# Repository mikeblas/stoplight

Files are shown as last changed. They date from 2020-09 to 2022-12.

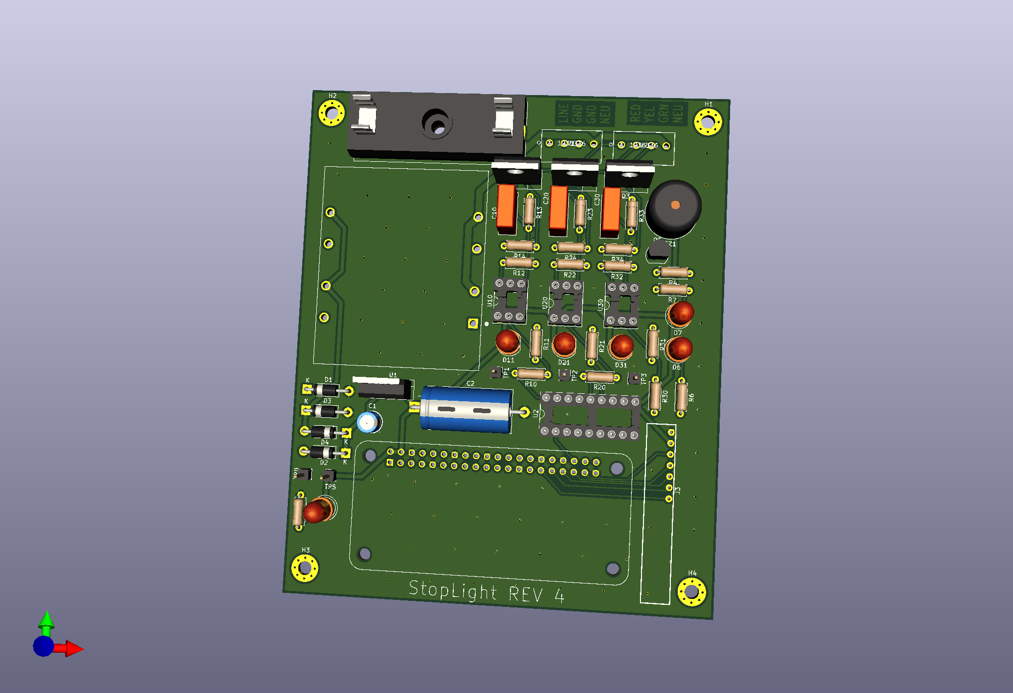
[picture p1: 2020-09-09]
pcb/StopLight4/StopLight4.png

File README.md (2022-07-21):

# stoplight
This project provides hardware and software for a stoplight controlled by a Raspberry Pi.

## Context
In the late 1990s, I purchased a traffic signal from a curiosities shop. It's a full-scale signal, appropriate for
"real" outdoor use; each lens is about 20cm in diameter, and it's a giant green beast. During the lockdowns in 2020,
I finally found the time to get it working in a fun and useful way.

This project includes a printed circuit board design that hosts a Raspberry Pi Zero W and implements a
mains-based power supply and switching circuits for each of the lamps in the signal. I chose the Pi Zero because
it gets me onto the wireless network, and has enough computing power to do interesting things with the signal. With
a little research, it should be possible to find a smaller board that has WiFi connectivity, but I already had an
unused Pi Zero, so I just went with it.

The board further hosts a generic wireless remote control board built around the PT2272 receiver chip. The chip
gives four latched outputs from a four-button key fob style RF remote. This remote can be used to control
the stoplight.

And of course, the project includes software to make it do something.

## Status

This project is "done enough" for now. All the features below are implemented, and the wish list features are
not yet implemented.

## Hardware Features

The hardware is done; amazingly, I didn't have to re-print the board and got it right on the first try. The
only problem was using a 7805 regulator. The voltage drop made it run red hot, so I replaced it with a three-pin
PC-based switching regulator, which works fine. The filter capacitor on the output of the supply wasn't adequate,
so I increased it. That, of course, required a part with a bigger footprint so the mounting is a bit lumpy,
but it works fine.

## Software Features

The software implements several modes, selectable by the remote. First, we can turn the thing off:

* Turn off the light; minimal processing, nothing illuminated.
* Turn the light back on; whatever mode was active last resumes.

Then, we have one of a few modes active:

* Traffic light. Red, green, yellow, in a realistically timed cycle.
* Random single flash. Flash a single (selectable) lamp at a regular interval.
* Random flash. Flash a randomly selected lamp one at a time.
* Random flash. Flash each lamp at random intervals. This is "disco mode"! 
* Manual selection. Turn a lamp off or on, and it stays that way.

We mostly leave the light in disco mode, and it's fun to see it blinking away.

## Wish List

I'd like to add a few more modes:

* Clock. Flash lights to make a binary time-of-day clock.
* Weather indicator. Show tomorrow's predicted weather (temperature and precipitation)
* Stock market indicator. If the market is open, show the directional change in a particular index.

There's also a couple of interesting things that I'd like to add:

* Mode memory. It would be great to have the system restore its mode when it starts up again after
a reboot or power failure.
* Monitoring. Anything I can monitor in my home network is monitored -- lots of SNMP collectors and
some Influx scripts pull data in to Grafana. Adding 
* Web page. It would be cool to have a little web server to present a UI for changing modes, looking
at statistics, and so on.
* Mobile app. A web API would enable a mobile application for modes and stats, too.

Since the project is built and installed, then I'm not very motivated to work on these things. Maybe
in the winter I'll get another Pi Zero and set it up so I can run the core on my bench, and get to
work on those feature. The design has on-board LEDs for all of the outputs, so pretty much no support
circuitry is necessary. I just need to build and populate one of my spare PC boards. 

## Project Layout

`stoplightd` is the stoplight daemon program. This is the controller that runs on the Pi (as I'm working on it)

`proto` are various fragments and scratch projects as I sort out GPIO, how the hardware works, and try out ideas.

`pcb` is the hardware project for KiCad.

## Images

Installing KiCad just to take a peek is a big ask, so here are some links:

* A snapshot of [the PC board](docs/pics/pc_board.png "PC Board")
* A snapshot of [the schematic](docs/pics/schematic.png "Schematic")

# Dependencies

This project uses [libdaemonize](https://github.com/Aethelflaed/libdaemonize).

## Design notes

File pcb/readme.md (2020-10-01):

# Stoplight Controller PC Board

This directory contains different versions of the StopLight PC Board. I split the design since I wasn't comfortable using `git` to manage the projects, and I also wasn't positive I wouldn't fork or rework the older designs anyway. I ended up linear, though, and StopLight4 is the version of the board sent to be fabricated.

## StopLight1

Uses discrete transistors to drive the relays and indicator LEDs.

## StopLight2

Substitutes a `ULN2803` driver chip for the relays to save a lot of space.

## StopLight3

Relays turned out to be pretty noisy, so I built a TRIAC circuit to drive the lights. Maybe the `ULN2803` isn't necessary anymore, but it remains. (Uhoh. Looks like some files are missing!)

## StopLight4

There were fuses on each of the three light lines, which is a bit redundant. Seems nice, but the fuse holders take up a ton of PC board space so I've eliminated them. This resulted in a more pleasing layout and a smaller board. This board version was sent to production.

## StopLight5

This version will fix a few issues, if another production run is needed:

1) Holes in remote header too smaller (0.75mm, should be 1.00mm)
2) Phoenix connectors are facing the wrong way
3) Rotate TP5 so its silk screen matches other TPs
4) Mask over the copper legend for high-voltage outputs
5) "hash" silkscreen over high voltage area of board
6) Renumber F4 to F1

# Hardware PostMortem

Most of the interesting problems are listed above, but some are not; and some are interesting to investigate a little more.

## Power Supply

Most of the issues were with the power supply, really.

**Power Budget**. I just figured I'd get a transformer, rectifier, a couple of filter caps, and drive a 7805 and be done. It's a little more complicated than that. First off, I bugeted a bit high for power because I thought I would be holding relays up. Once I eliminated the relays, I shouldn't made a closer estimate. The supply should drive about 1.5 amps without a problem (except for heat), and I could use a much smaller transformer since my budget is really closer to 500 milliamps.

**Filter**. I couldn't find good advice about sizing the filter caps, and they're too small. Maybe the over-arching problem is that I didn't prototype the power supply on my breadboard. Had I done so, I would've caught most (if not all) of these problems.

**Heat**. My transformer develops 10 volts at the secondary, which initially sounded low. The dropout of the regulator means I need at least 7 volts at the input, and I'm making lots of heat in the linear regulator. A switching regulator is probably the best solution, and I'm probably going to end up getting one of the "cheater" switching converters on a TO-220-sized board to solve the heat issue.

## Layout

I'm pretty pleased with the layout. I was always tempted to "hide" components under the Raspberry Pi module, but I'm glad I didn't because it would  have made troubleshooting harder. Getting a probe onto anything under there would be obnoxious -- my only choice would be to get to the back of the board.

After that, the layout is pretty nice. I'm glad I got rid of the redundant fuses. It might have helped more the use an in-line fuse holder, but those also have some inconveniences. A smaller fuse form factor might have been a good idea, tho.

## In General

It was great to get rid of the relays. The clicking was completely obnoxious; I can't imagine these being used in anything but an industrial or large commercial application. Learning how to control the TRIACS was fun. 

I could probably get rid of the driver, but it's not much real estate and gives me a bit more confidence in the design for now.

## Software

The software is going well, though I don't have as much time to spend on it. When I do, I'm productive and can get some things done.

## Mechanical

The mechanical assembly came together quite well, and I'm happy with it. Even the carpentry isn't so bad.

## Light Bulbs

I'm worried that the light is too bright. Maybe a cool V2 feature would be to support PWM dimming so the brightness would be settable through software. Choosing bulbs was hard; there aren't many incadescent choices anymore. LED bulbs don't go so dim, either. The 25-watt equivalent LED bulb seems best, but it's quite expensive (about $8) and who knows how long they'll make it. A couple LED bulbs I tried didn't turn on or off correctly, so experimenting is kind of hit-and-miss.

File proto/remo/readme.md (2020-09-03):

== remo ==

A first cut at readingt the RF remote inputs from the GPIO.

This polls, which is kind of lame -- and I need to sort out the object structure.

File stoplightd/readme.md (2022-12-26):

# stoplightd

The daemon runs the stoplight. It listens to the remote and blinks lights -- it's almost that simple!

It logs, too, to syslog. And it can run the stoplight in a bunch if different modes. Since the remote is klunky and unreliable, and because the light only has a beeper and the three traffic lights, we have to be creative about UI.

When the light is in **idle** mode, it is dark. It's not beeping, and all the lights are off. Idle mode can be exited with any button press; any button pres moves to **selection** mode.

So now let's examine the different modes:

## Selection
Selection mode lets the user select a mode.

* Binary display to select mode. A is up, B is down. When zero, red flashes 100 ms every 2 seconds (or so?)
* C selects mode.
* D exits to idle mode.
	
## Mode 0: Plain traffic light	
* A increases speed,
* B decreases speed. Speed is ratio of R48/Y8/G24 (6x, 1x, 4x), 1 second steps, 1-10
* D quits back to mode selection.

## Mode 1: Single Blinky	
* A increases speed, B decreases speed. 250ms to 5s in 250ms increments
* C sets duty cycle, looping through 100, 75, 50, 25%
* D quits back to mode selection.
	
## Mode 2: Multi Blinky
* A increases speed, B decreases speed. 250ms to 5s in 250ms increments
* C sets duty cycle, looping through 100, 75, 50, 25%
* D quits back to mode selection.

## Mode 3: Selecto
* A, B, C toggles each light
* D quits back to mode selection

## Mode 4: Clock
 * All off, but every 30 sconds shows time
 * flashes Hour, then minute in binary.
 * D quits

This is how numbers are displayed:
 * 0-7: binary; 1 = ryG, 3 = rYG, 4 = Ryg
 * 8: rapidly flashing red, y = off, g = on
 * 9: rapidly flashing red, y = on, g = off
 * each digit shown 1 second, display of 4 digits takes 4 seconds

## Mode 5: Weather
 * Temperature change for 2 seconds
 * Precip chance for 3 seconds  (green = 0-20%, yel= 20-60%, red > 60%)
 * 5 seconds dark
 * D quits

## Mode 6: Stock Ticker

(Not yet implemented.)

## Mode 7: Weather

(Not yet implemented.)

# Building

This project requires [libdaemonize](https://github.com/Aethelflaed/libdaemonize) and gpiod.

## libdaemonize

1. Clone the `libdaemonize` project from git.
2. It requires `libtool` to get working, so install that with `sudo apt install libtool -y`
3. In the `libdaemonize` root directory, run these commands:  
```
libtoolize
aclocal
autoconf
automake --add-missing
```
4. Now, the library can be configured and built:
```
./configure --prefix=/usr
make
```
5. And finally installed, so that the library and its headers are readable.
```
sudo make install
```

## libgpiod

The code needs `libgpiod` to communicate with the Raspberry Pi GPIO. It can be installed easily:

```
sudo apt install libgpiod-dev -y
``` 

## Actually building

With the dependencies installed and built, the project itself can be built:

```
make clean all
```

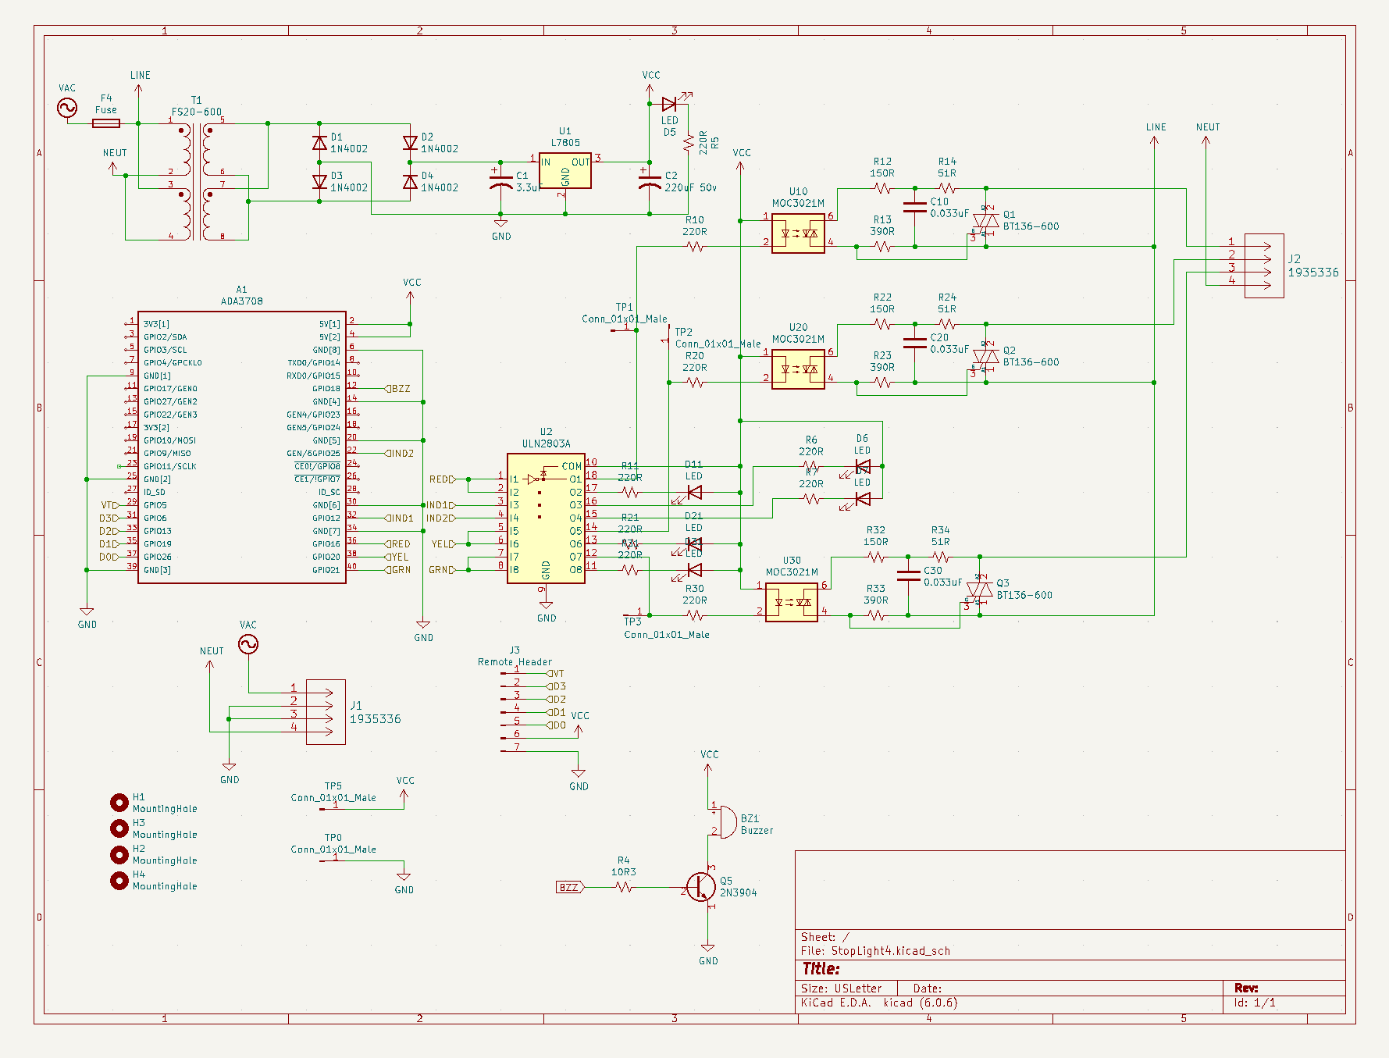
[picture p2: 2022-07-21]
docs/pics/schematic.png

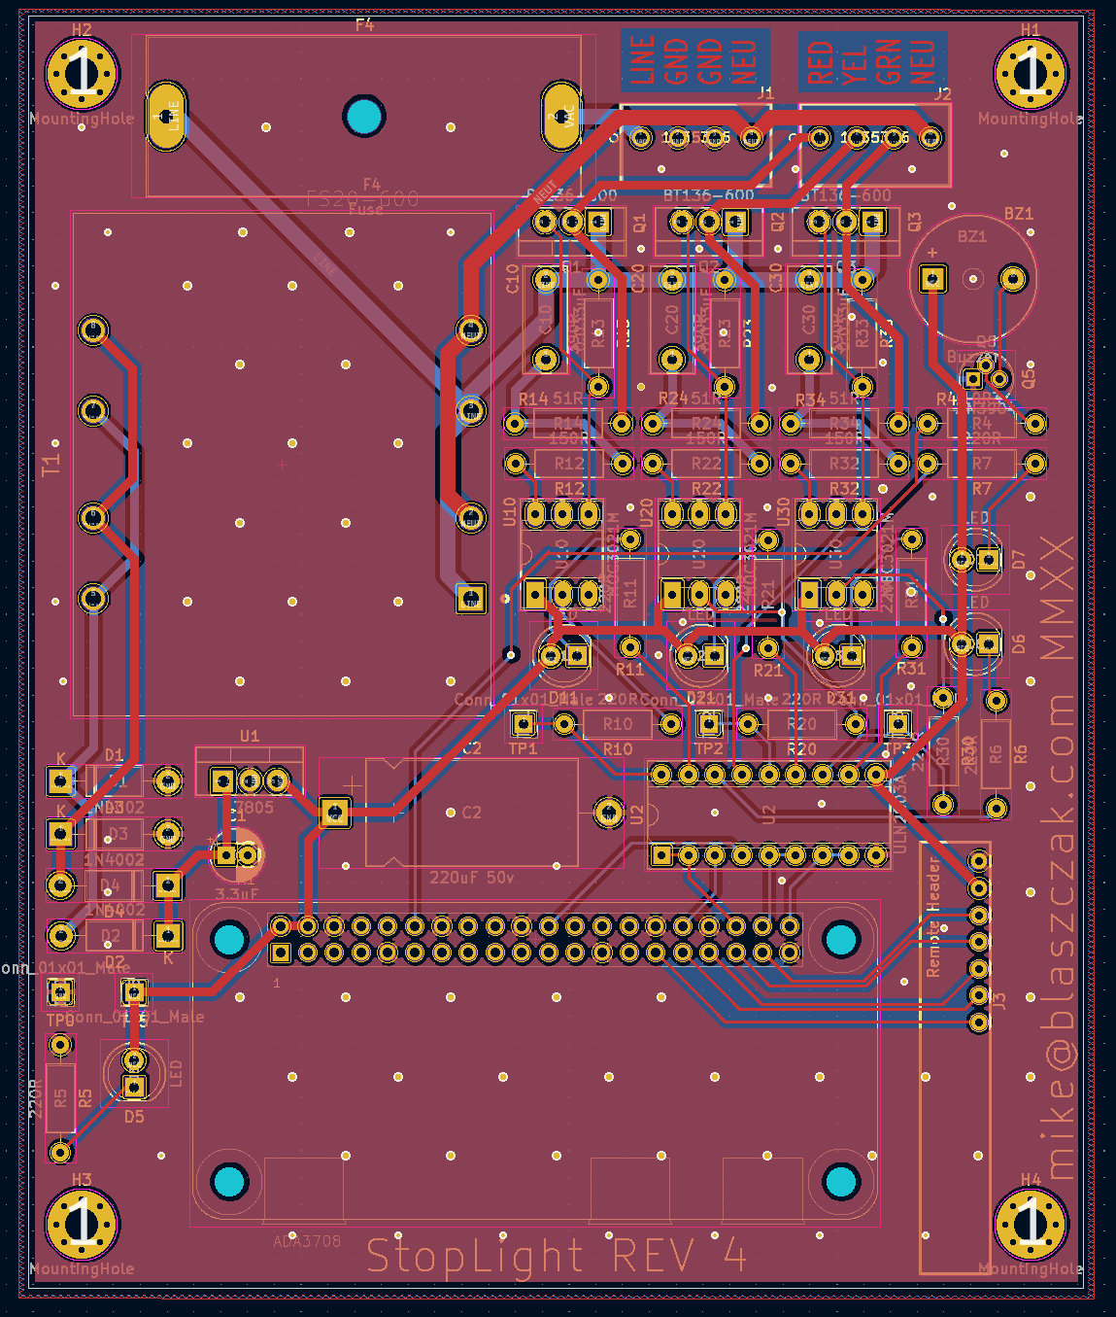
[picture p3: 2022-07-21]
docs/pics/pc_board.png

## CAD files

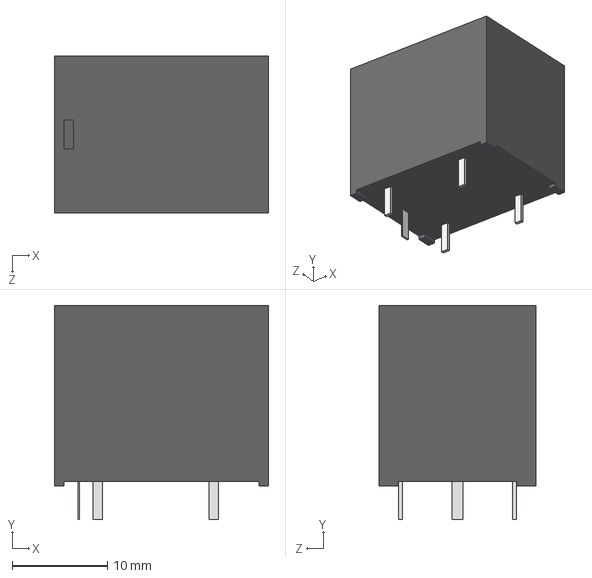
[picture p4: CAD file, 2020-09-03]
pcb/StopLight1/G5LE_14.step
22.5 x 22.5 x 16.5 mm

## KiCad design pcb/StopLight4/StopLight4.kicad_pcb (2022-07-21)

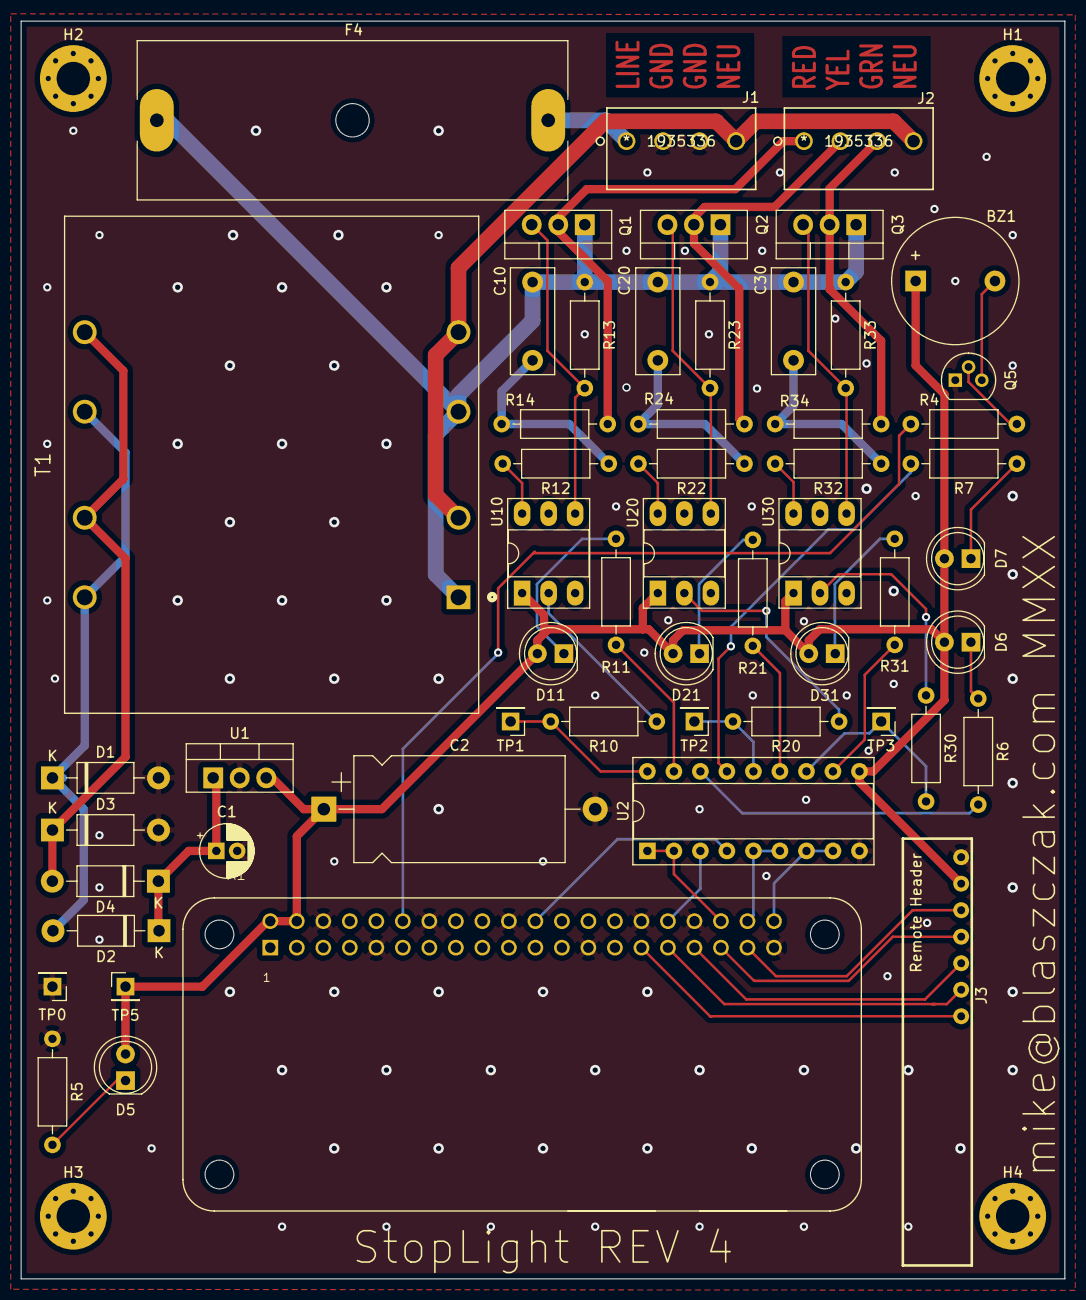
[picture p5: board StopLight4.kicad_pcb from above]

Board: 2 copper layers, 100.0 x 120.5 mm, 59 parts (0 on the bottom side), 50 nets.

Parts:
A1: ADA3708; ADA3708_RPI-ZERO
BZ1: Buzzer; Buzzer_12x9.5RM7.6
C1: 3.3uF; CP_Radial_D5.0mm_P2.00mm
C2: 220uF 50v; CP_Axial_L20.0mm_D10.0mm_P26.00mm_Horizontal
C10, C20, C30: 0.033uF; C_Rect_L10.0mm_W4.0mm_P7.50mm_MKS4
D1, D2, D3, D4: 1N4002; D_DO-41_SOD81_P10.16mm_Horizontal
D5, D6, D7, D11, D21, D31: LED; LED_D5.0mm
F4: Fuse; Fuseholder_Cylinder-6.3x32mm_Schurter_0031-8002_Horizontal_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
H1, H2, H3, H4: MountingHole; MountingHole_3.2mm_M3_Pad_Via
J1, J2: 1935336; 1984633
J3: Remote Header; WirelessRemote
Q1, Q2, Q3: BT136-600; TO-220-3_Vertical
Q5: 2N3904; TO-92
R4: 10R3; R_Axial_DIN0207_L6.3mm_D2.5mm_P10.16mm_Horizontal
R5, R6, R7, R10, R11, R20, R21, R30, R31: 220R; R_Axial_DIN0207_L6.3mm_D2.5mm_P10.16mm_Horizontal
R12, R22, R32: 150R; R_Axial_DIN0207_L6.3mm_D2.5mm_P10.16mm_Horizontal
R13, R23, R33: 390R; R_Axial_DIN0207_L6.3mm_D2.5mm_P10.16mm_Horizontal
R14, R24, R34: 51R; R_Axial_DIN0207_L6.3mm_D2.5mm_P10.16mm_Horizontal
T1: FS20-600; XFMR_FS20-600
TP0, TP1, TP2, TP3, TP5: Conn_01x01_Male; PinHeader_1x01_P2.54mm_Vertical
U1: L7805; TO-220-3_Vertical
U2: ULN2803A; DIP-18_W7.62mm_Socket
U10, U20, U30: MOC3021M; DIP-6_W7.62mm_Socket_LongPads

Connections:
/D0: A1.37, J3.5
/D1: A1.35, J3.4
/D2: A1.33, J3.3
/D3: A1.31, J3.2
/GRN: A1.40, U2.7, U2.8
/IND1: A1.32, U2.3
/IND2: A1.22, U2.4
/RED: A1.36, U2.1, U2.2
/VT: A1.29, J3.1
/YEL: A1.38, U2.5, U2.6
BZZ: A1.12, R4.2
GND: A1.6, A1.9, A1.14, A1.20, A1.25, A1.30, A1.34, A1.39, C1.2, C2.2, D1.2, D3.2, J1.2, J1.3, J3.7, Q5.1, R5.1, TP0.1, U1.2, U2.9
LINE: C10.2, C20.2, C30.2, F4.1, Q1.1, Q2.1, Q3.1, R13.1, R23.1, R33.1, T1.1, T1.3
NEUT: J1.4, J2.4, T1.2, T1.4
unnamed: BZ1.2, Q5.3
unnamed: C1.1, D2.1, D4.1, U1.1
unnamed: C10.1, R12.1, R14.2
unnamed: C20.1, R22.1, R24.2
unnamed: C30.1, R32.1, R34.2
unnamed: D1.1, D2.2, T1.5, T1.7
unnamed: D3.1, D4.2, T1.6, T1.8
unnamed: D5.1, R5.2
unnamed: D6.1, R6.1
unnamed: D7.1, R7.1
unnamed: D11.1, R11.1
unnamed: D21.1, R21.1
unnamed: D31.1, R31.1
unnamed: J2.1, Q1.2, R14.1
unnamed: J2.2, Q2.2, R24.1
unnamed: J2.3, Q3.2, R34.1
unnamed: Q1.3, R13.2, U10.4
unnamed: Q2.3, R23.2, U20.4
unnamed: Q3.3, R33.2, U30.4
unnamed: Q5.2, R4.1
unnamed: R6.2, U2.16
unnamed: R7.2, U2.15
unnamed: R10.1, U10.2
unnamed: R10.2, TP1.1, U2.18
unnamed: R11.2, U2.17
unnamed: R12.2, U10.6
unnamed: R20.1, U20.2
unnamed: R20.2, TP2.1, U2.14
unnamed: R21.2, U2.13
unnamed: R22.2, U20.6
unnamed: R30.1, U30.2
unnamed: R30.2, TP3.1, U2.12
unnamed: R31.2, U2.11
unnamed: R32.2, U30.6
VAC: F4.2, J1.1
VCC: A1.2, A1.4, BZ1.1, C2.1, D5.2, D6.2, D7.2, D11.2, D21.2, D31.2, J3.6, TP5.1, U1.3, U2.10, U10.1, U20.1, U30.1

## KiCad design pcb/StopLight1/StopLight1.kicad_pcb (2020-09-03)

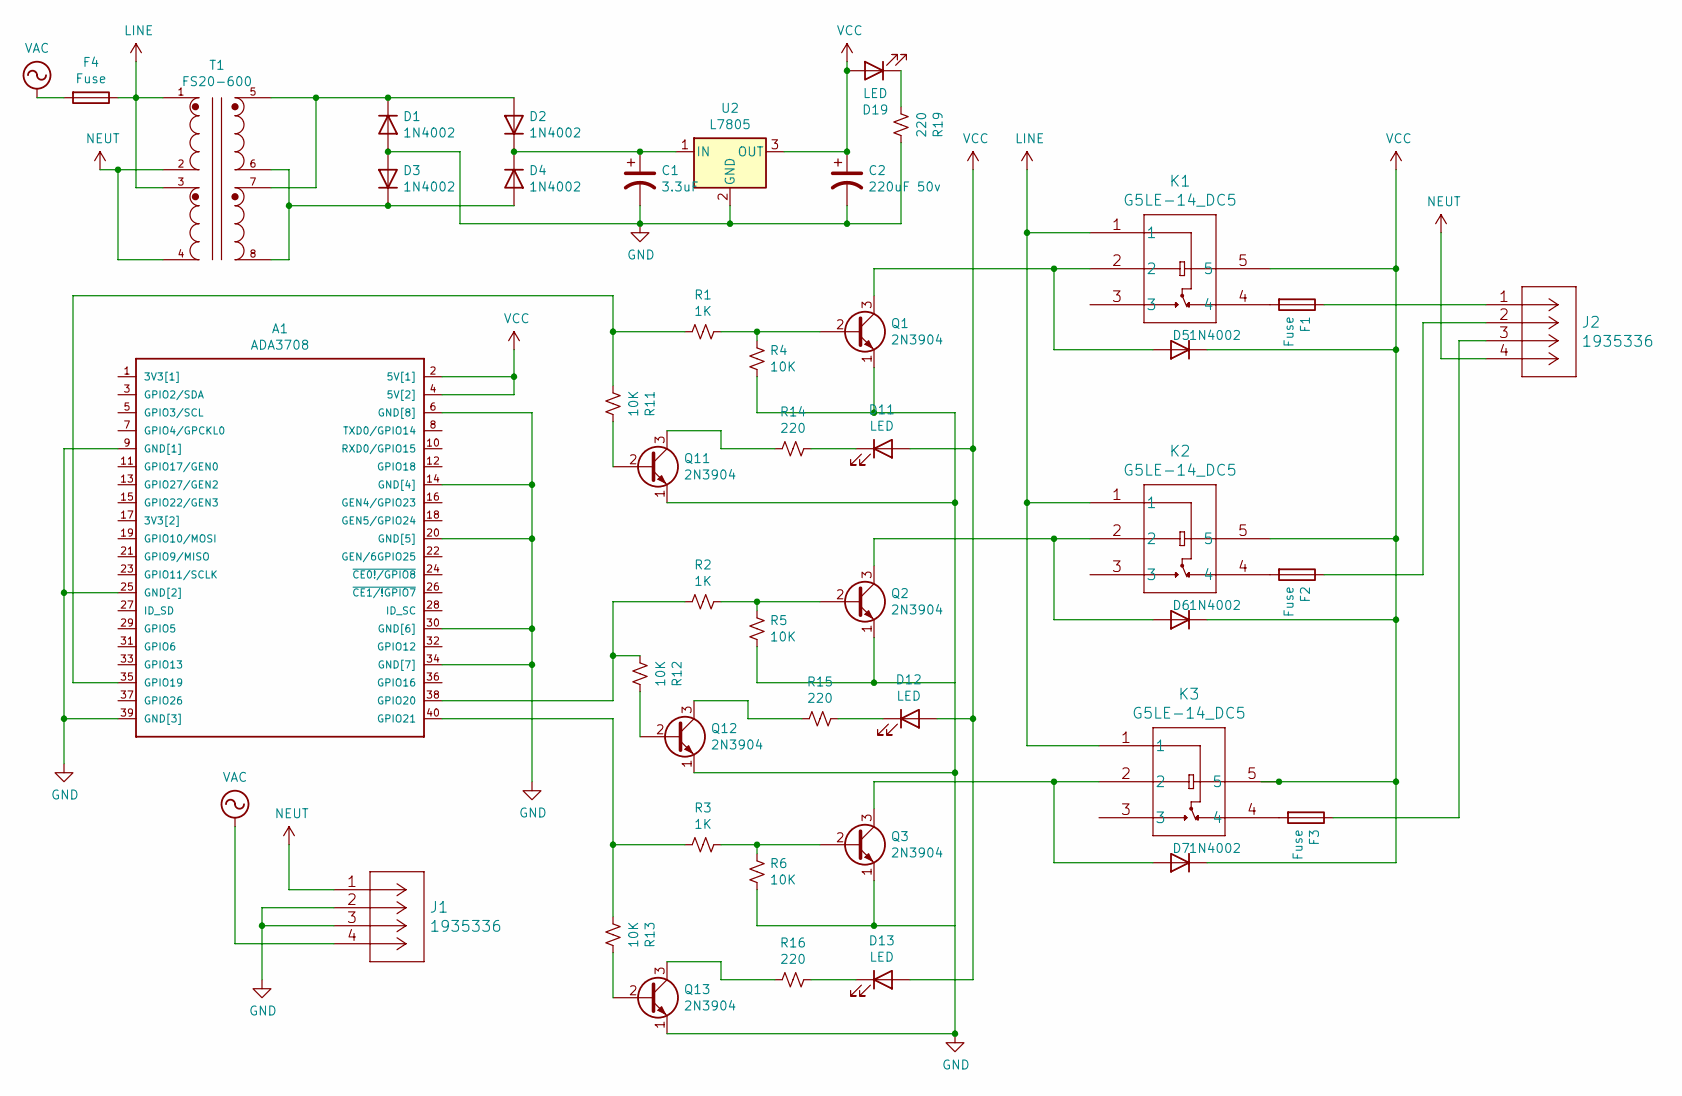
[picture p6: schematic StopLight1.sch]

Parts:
A1: ADA3708; ADA3708_RPI-ZERO
C1: 3.3uF; CP_Radial_D5.0mm_P2.00mm
C2: 220uF 50v; CP_Axial_L20.0mm_D10.0mm_P26.00mm_Horizontal
D1, D2, D3, D4, D5, D6, D7: 1N4002; D_DO-41_SOD81_P10.16mm_Horizontal
D11, D12, D13, D19: LED; LED_D5.0mm
F1, F2, F3, F4: Fuse; Fuseholder_Cylinder-6.3x32mm_Schurter_0031-8002_Horizontal_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
J1, J2: 1935336
K1, K2, K3: G5LE-14_DC5; G5LE-14 DC5
Q1, Q2, Q3, Q11, Q12, Q13: 2N3904; TO-92
R1, R2, R3: 1K; R_Axial_DIN0207_L6.3mm_D2.5mm_P10.16mm_Horizontal
R4, R5, R6, R11, R12, R13: 10K; R_Axial_DIN0207_L6.3mm_D2.5mm_P10.16mm_Horizontal
R14, R15, R16, R19: 220; R_Axial_DIN0207_L6.3mm_D2.5mm_P10.16mm_Horizontal
T1: FS20-600; XFMR_FS20-600
U2: L7805; TO-220-3_Vertical

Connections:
GND: A1.6 (GND[8]), A1.9 (GND[1]), A1.14 (GND[4]), A1.20 (GND[5]), A1.25 (GND[2]), A1.30 (GND[6]), A1.34 (GND[7]), A1.39 (GND[3]), C1.2, C2.2, D1.2 (A), D3.2 (A), J1.2, J1.3, Q1.1 (E), Q11.1 (E), Q12.1 (E), Q13.1 (E), R4.2, R19.1, U2.2 (GND)
LINE: F4.1, K1.1, K2.1, K3.1, T1.1, T1.3
NEUT: J1.1, J2.4, T1.2, T1.4
unnamed: A1.35 (GPIO19), R1.2, R11.2
unnamed: A1.38 (GPIO20), R2.2, R12.2
unnamed: A1.40 (GPIO21), R3.2, R13.2
unnamed: C1.1, D2.1 (K), D4.1 (K), U2.1 (IN)
unnamed: D1.1 (K), D2.2 (A), T1.5, T1.7
unnamed: D3.1 (K), D4.2 (A), T1.6, T1.8
unnamed: D5.2 (A), K1.2, Q1.3 (C)
unnamed: D6.2 (A), K2.2, Q2.3 (C)
unnamed: D7.2 (A), K3.2, Q3.3 (C)
unnamed: D11.1 (K), R14.1
unnamed: D12.1 (K), R15.1
unnamed: D13.1 (K), R16.1
unnamed: D19.1 (K), R19.2
unnamed: F1.1, J2.1
unnamed: F1.2, K1.4
unnamed: F2.1, J2.2
unnamed: F2.2, K2.4
unnamed: F3.1, J2.3
unnamed: F3.2, K3.4
unnamed: Q1.2 (B), R1.1, R4.1
unnamed: Q2.1 (E), R5.2
unnamed: Q2.2 (B), R2.1, R5.1
unnamed: Q3.1 (E), R6.2
unnamed: Q3.2 (B), R3.1, R6.1
unnamed: Q11.2 (B), R11.1
unnamed: Q11.3 (C), R14.2
unnamed: Q12.2 (B), R12.1
unnamed: Q12.3 (C), R15.2
unnamed: Q13.2 (B), R13.1
unnamed: Q13.3 (C), R16.2
VAC: F4.2, J1.4
VCC: A1.2 (5V[1]), A1.4 (5V[2]), C2.1, D5.1 (K), D6.1 (K), D7.1 (K), D11.2 (A), D12.2 (A), D13.2 (A), D19.2 (A), K1.5, K2.5, K3.5, U2.3 (OUT)

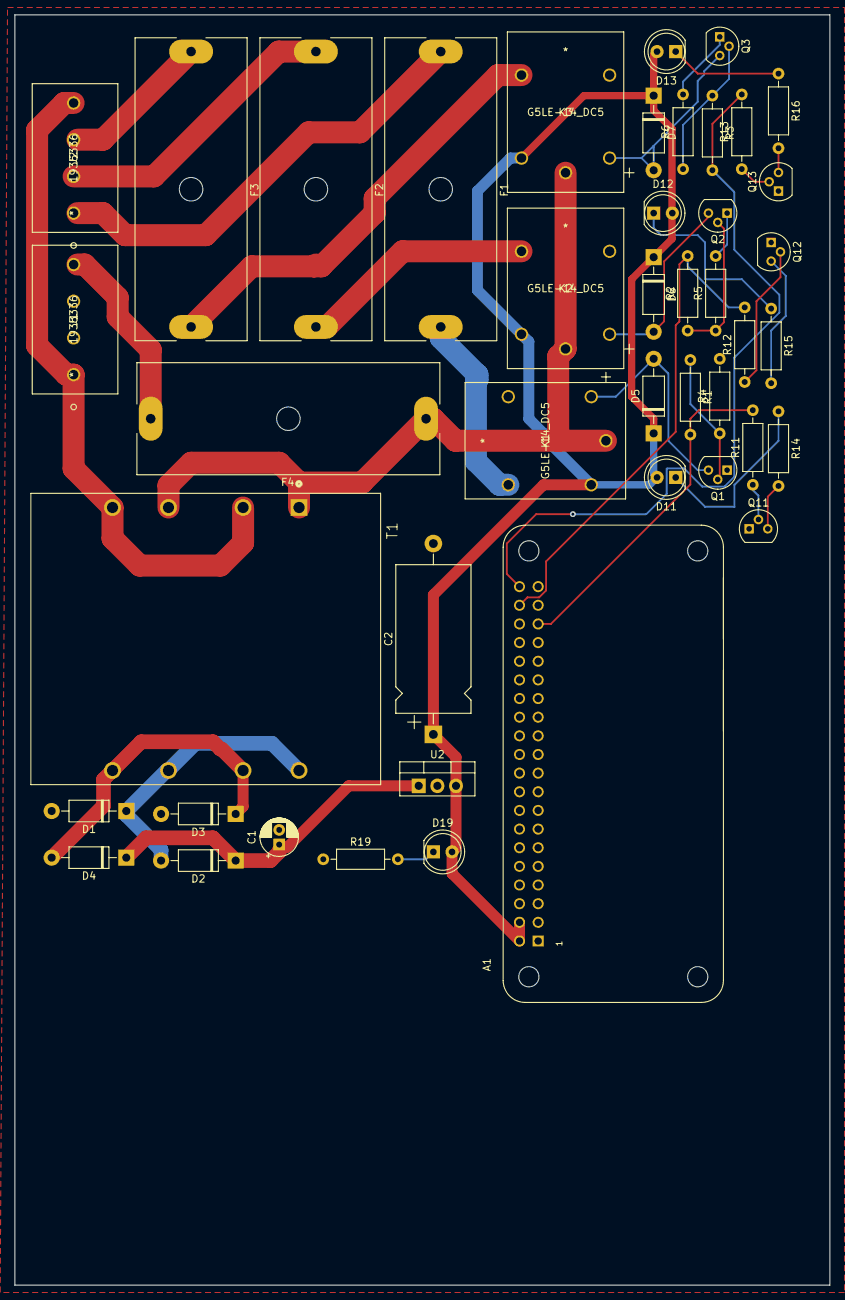
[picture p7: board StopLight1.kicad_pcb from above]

Board: 2 copper layers, 111.0 x 173.0 mm, 44 parts (0 on the bottom side), 35 nets.

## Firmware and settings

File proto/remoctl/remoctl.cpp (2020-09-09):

#include <stdio.h>
#include <stdlib.h>
#include <unistd.h>
#include <gpiod.h>
#include <time.h>

// the gpiod library uses the BCM line numbers!

static const char* STOPLIGHT_CLIENT = "stoplight_remo";

class Buttons
{

private:
	struct gpiod_line* line5;
	struct gpiod_line* line6;
	struct gpiod_line* line13;
	struct gpiod_line* line19;
	struct gpiod_line* line26;

	int val5;
	int val6;
	int val13;
	int val19;
	int val26;

public:
	Buttons(struct gpiod_chip* chip) {
		line5  = gpiod_chip_get_line(chip, 5);
		line6  = gpiod_chip_get_line(chip, 6);
		line13 = gpiod_chip_get_line(chip, 13);
		line19 = gpiod_chip_get_line(chip, 19);
		line26 = gpiod_chip_get_line(chip, 26);

		gpiod_line_request_input(line5, STOPLIGHT_CLIENT);
		gpiod_line_request_input(line6, STOPLIGHT_CLIENT);
		gpiod_line_request_input(line13, STOPLIGHT_CLIENT);
		gpiod_line_request_input(line19, STOPLIGHT_CLIENT);
		gpiod_line_request_input(line26, STOPLIGHT_CLIENT);
	}

	void ReadLines() {

		val5 = gpiod_line_get_value(line5);
		val6 = gpiod_line_get_value(line6);
		val13 = gpiod_line_get_value(line13);
		val19 = gpiod_line_get_value(line19);
		val26 = gpiod_line_get_value(line26);
	}

	int GetAButton() const {
		return val26;
	}

	int GetBButton() const {
		return val19;
	}

	int GetCButton() const {
		return val13;
	}

	int GetDButton() const {
		return val6;
	}

	int GetVT() const {
		return val5;
	}

	bool operator==(const Buttons& other) const {
		if (GetAButton() != other.GetAButton())
			return false;
		if (GetBButton() != other.GetBButton())
			return false;
		if (GetCButton() != other.GetCButton())
			return false;
		if (GetDButton() != other.GetDButton())
			return false;
		return true;
	}

	bool operator!=(const Buttons& other) const {
		return !operator==(other);
	}

	void operator=(const Buttons& other) {
		val5 = other.val5;
		val6 = other.val6;
		val19 = other.val19;
		val26 = other.val26;
		val13 = other.val13;
	}
};


class Buzzer {
	struct gpiod_line* lineBuzz;

public:
	Buzzer(struct gpiod_chip* chip) {

		lineBuzz = gpiod_chip_get_line(chip, 25);

		gpiod_line_request_output(lineBuzz, STOPLIGHT_CLIENT, 0);
	}

	void On() {
		gpiod_line_set_value(lineBuzz, 1);
	}

	void Off() {
		gpiod_line_set_value(lineBuzz, 0);
	}
};


class Lights {

	struct gpiod_line* lineRed;
	struct gpiod_line* lineYellow;
	struct gpiod_line* lineGreen;

public:
	Lights(struct gpiod_chip* chip) {
		lineRed  = gpiod_chip_get_line(chip, 21);
		lineYellow  = gpiod_chip_get_line(chip, 20);
		lineGreen  = gpiod_chip_get_line(chip, 16);

		gpiod_line_request_output(lineRed, STOPLIGHT_CLIENT, 0);
		gpiod_line_request_output(lineYellow, STOPLIGHT_CLIENT, 0);
		gpiod_line_request_output(lineGreen, STOPLIGHT_CLIENT, 0);
	}

	void AllOff() {
		SetRed(0);
		SetYellow(0);
		SetGreen(0);
	}

	void AllOn() {
		SetRed(1);
		SetYellow(1);
		SetGreen(1);
	}

	void SetRed(int state) {
		gpiod_line_set_value(lineRed, state);
	}

	void SetYellow(int state) {
		gpiod_line_set_value(lineYellow, state);
	}

	void SetGreen(int state) {
		gpiod_line_set_value(lineGreen, state);
	}

	void ToggleRed() {
		int state = gpiod_line_get_value(lineRed);
		SetRed(!state);
	}

	void ToggleYellow() {
		int state = gpiod_line_get_value(lineYellow);
		SetYellow(!state);
	}

	void ToggleGreen() {
		int state = gpiod_line_get_value(lineGreen);
		SetGreen(!state);
	}

	void FlickAll(int count, int millis) {

		AllOff();
		for (int n = 0; n < count; ++n) {
			usleep(1000 * millis);
			AllOn();
			usleep(1000 * millis);
			AllOff();
		}
	}
};

int main(void)
{
	printf("gpiod version: %s\n", gpiod_version_string());

	static const char* chipname = "gpiochip0";

	struct gpiod_chip* chip = gpiod_chip_open_by_name(chipname);
	if (chip == nullptr) {
		perror("Open chip failed\n");
		goto end;
	}
	else
	{
		Lights lights(chip);
		Buzzer buzz(chip);

		buzz.On();
		lights.FlickAll(3, 50);
		buzz.Off();

		Buttons b1(chip);
		b1.ReadLines();
		int lastVT = b1.GetVT();
		int ignores = 0;
		int buzzticks = 0;

		while(1) {

			if (buzzticks > 0) {
				if (--buzzticks == 0) {
					buzz.Off();
				}
			}

			if (ignores > 0) {
				ignores--;
			} else {

				buzz.Off();

				Buttons b2(chip);
				b2.ReadLines();

				// anything change since last time?
				if (b2 != b1 || lastVT != b2.GetVT()) {

					// yes! print out the flags
					printf("b1 = %d, %d, %d, %d, %d\n", b1.GetAButton(), b1.GetBButton(), b1.GetCButton(), b1.GetDButton(), b1.GetVT());
					printf("b2 = %d, %d, %d, %d, %d\n", b2.GetAButton(), b2.GetBButton(), b2.GetCButton(), b2.GetDButton(), b2.GetVT());

					// ignore three loops to debounce
					ignores = 3;

					// if this is a release decide what to do
					if (b2.GetVT() == 1) {
						buzz.On();
						buzzticks = 1;

						printf("***\n");
						if (b2.GetAButton()) {
							lights.ToggleRed();
						}
						if (b2.GetBButton()) {
							lights.ToggleYellow();
						}
						if (b2.GetCButton()) {
							lights.ToggleGreen();
						}
					}

					// change states
					b1 = b2;
					lastVT = b2.GetVT();
				}
			}

			usleep(100 * 1000);
		}
	}

end:
	return 0;
}

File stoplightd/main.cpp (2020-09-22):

#include <unistd.h>

#include <daemonize/daemonizer.hpp>
#include <daemonize/syslog.hpp>
#include <daemonize/signals.hpp>

#include "stoplightd.h"

int main(int /* argc */, const char** /* argv */)
{

   daemonize::syslog syslog("stoplightd");
   daemonize::signals::enable(&syslog);

   try
   {
      stoplightd d(syslog);
      daemonize::daemonizer(d);
   }
   catch(int status)
   {
      syslog << syslog.critical << "exiting with status " << status << std::endl;
      return status;
   }
   catch(...)
   {

      syslog << syslog.critical << "exiting with exception!" << std::endl;
      return EXIT_FAILURE;
   }

   return EXIT_SUCCESS;
}

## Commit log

2020-09-03 add PCB projects
    [G5LE_14.step, StopLight1.kicad_pcb, StopLight1.sch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]
2020-09-03 first cut at remote reading
2020-09-06 PC Board design is getting close
    [StopLight3.kicad_pcb, StopLight3.sch]
2020-09-09 Smaller PCB, sent to production!
    [StopLight3.kicad_pcb, StopLight4.kicad_pcb, StopLight4.sch]
2020-09-09 delay to let remote inputs stabilize
    [remo.cpp]
2020-09-10 tighten up makefiles
2020-09-11 first cut at a daemon
2020-09-13 turn on warnings, fix them up
    [demon1.cpp, flick.cpp, gp.cpp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]
2020-09-17 handle press/release in framework loop
2020-09-17 fix gitignore, clean up makefile a bit
    [stoplightd.cpp]
2020-09-17 refactor daemon itself, fix up makefile, split function
    [main.cpp, stoplightd.cpp]
2020-09-18 add modefactory, hook up mode switching (almost works)
2020-09-18 mode switching mostly works
2020-09-18 cleanup, reset lights between modes
    [stoplightd.cpp]
2020-09-19 fix key rollover when waking up from idle
    [stoplightd.cpp]
2020-09-23 update PCB readme with some notes
2020-09-30 change buzzer to match PCB; generate assembly listings
    just curious about output assembly, so make listings
2020-10-01 add C button to regular mode to select speed
2020-10-01 fix indentation, spacing in lights.h
    [lights.h, stoplightd.cpp]
2020-12-05 add comparitor to switch between seconds in minutes in clock mode
    this makes testing easier (for the less patient)
2021-02-03 setup service install
    add a service file, install target to makefile
    switch around pid file name
2022-07-21 update docs and status, add pictures
    [StopLight4.kicad_pcb, StopLight4.kicad_sch]

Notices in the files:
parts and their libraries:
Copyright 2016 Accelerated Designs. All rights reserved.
